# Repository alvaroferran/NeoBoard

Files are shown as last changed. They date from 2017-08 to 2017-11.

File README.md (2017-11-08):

# NeoBoard

<p align="center">
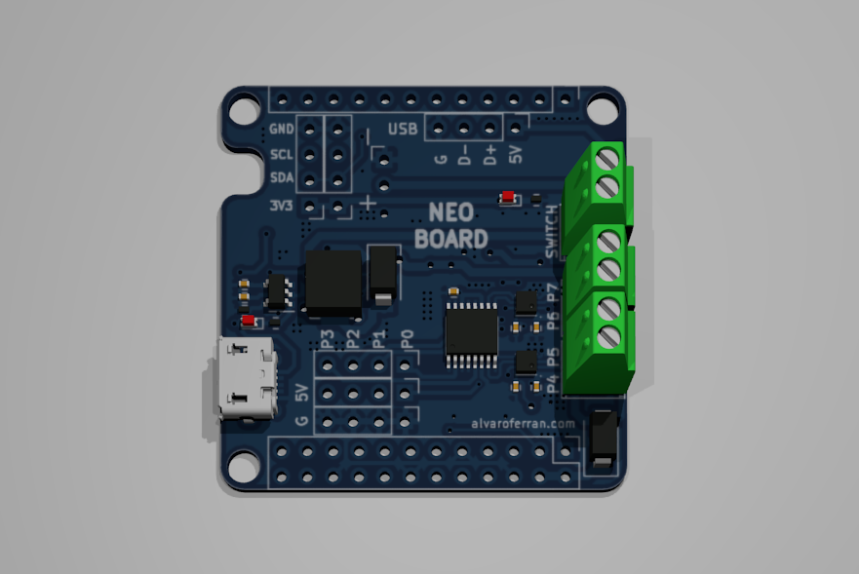
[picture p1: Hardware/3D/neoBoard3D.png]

</p>

<br>

NeoBoard is a robotics controller shield for the [NanoPi Neo Air](http://nanopi.io/nanopi-neo-air.html) SBC. It can drive two DC motors, has four extra 5V GPIOs and an ADC to read the battery level from the Linux board. It also includes a 1S LiPo battery charger, a 3.5A boost circuit to ramp the voltage up to 5V for the motors and a hardware-based motor disconnect in case of low battery.

<p align="center">
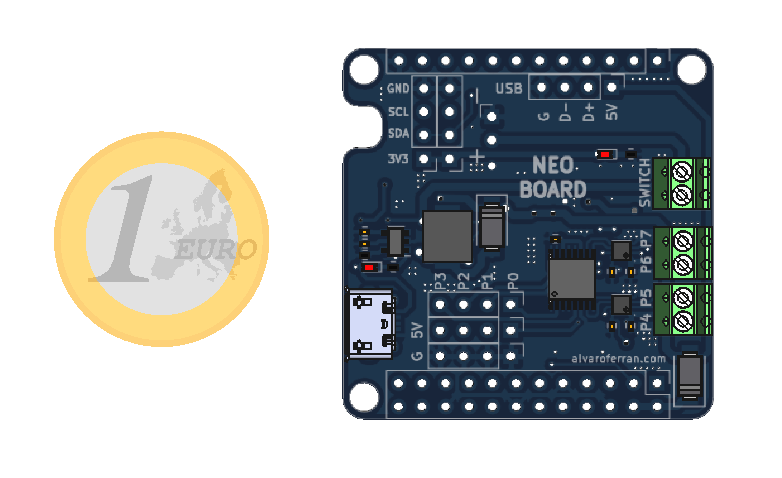
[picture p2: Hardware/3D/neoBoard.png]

</p>

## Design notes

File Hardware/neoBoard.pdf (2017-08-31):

# 3.3V REG

# J2USB BAT CHARGER

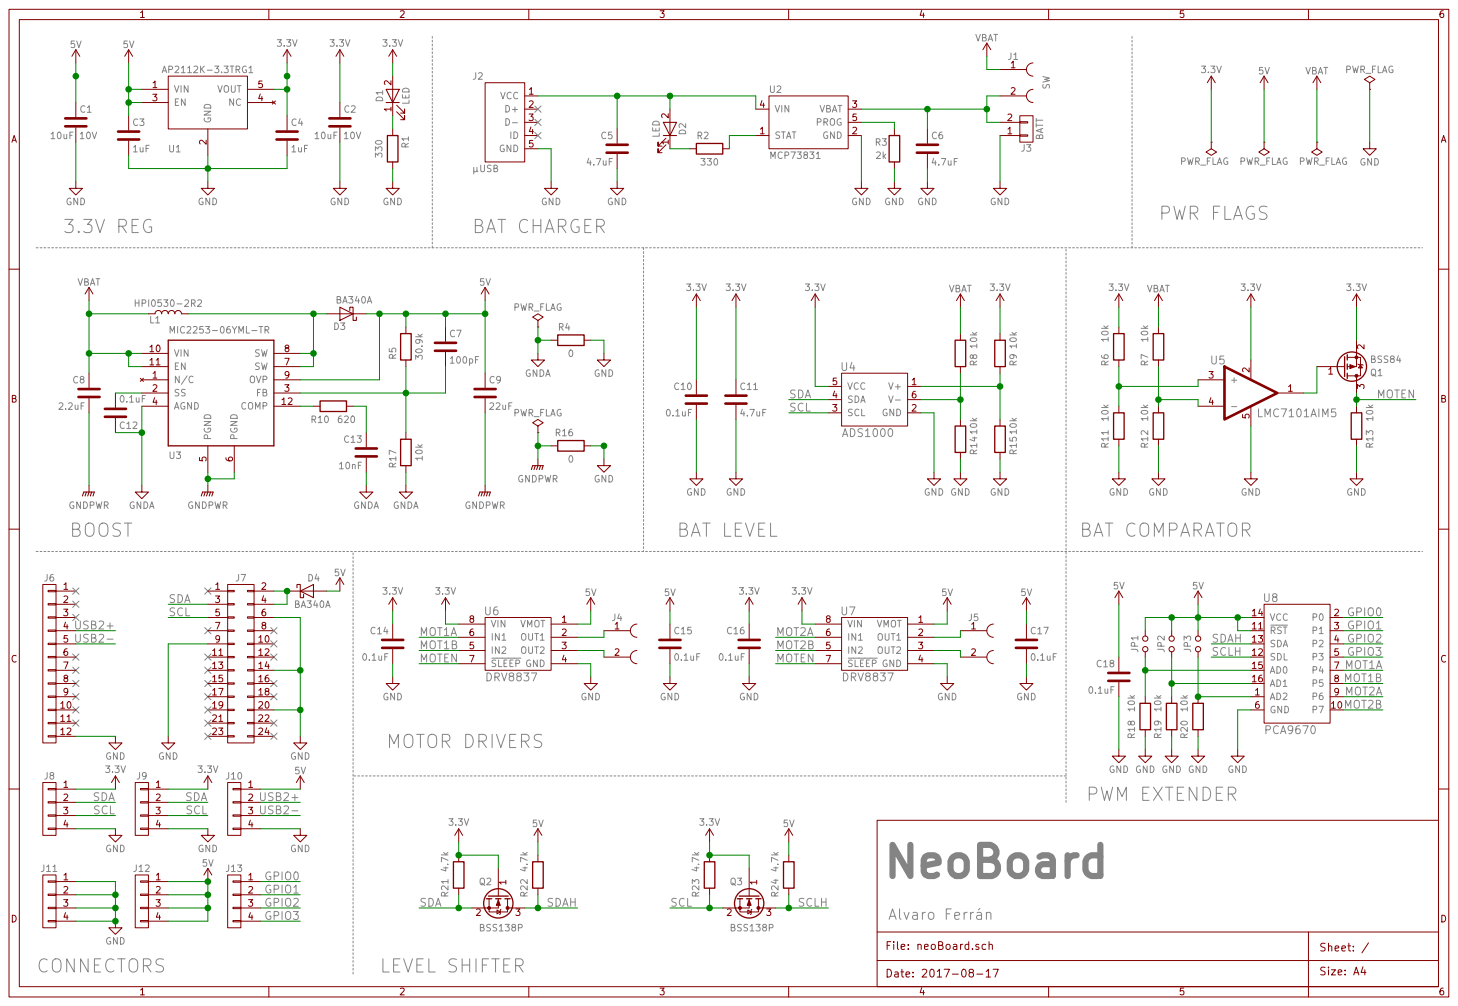
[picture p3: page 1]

6 SW 7 SW 8 OVP 9 VIN 10 EN 11 COMP 12 N/C 1 U3MIC2253-06YML-TR D3BA340A GNDPWR GNDA GNDPWR GNDA GNDA GNDPWR BOOST

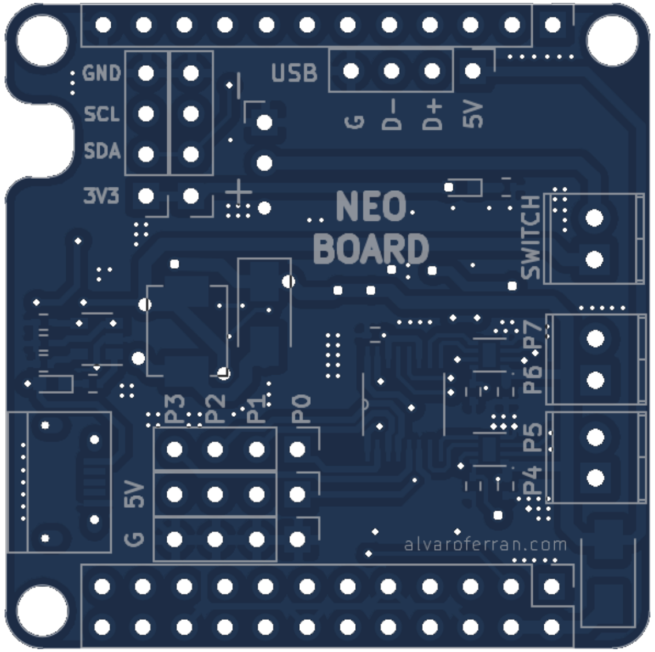
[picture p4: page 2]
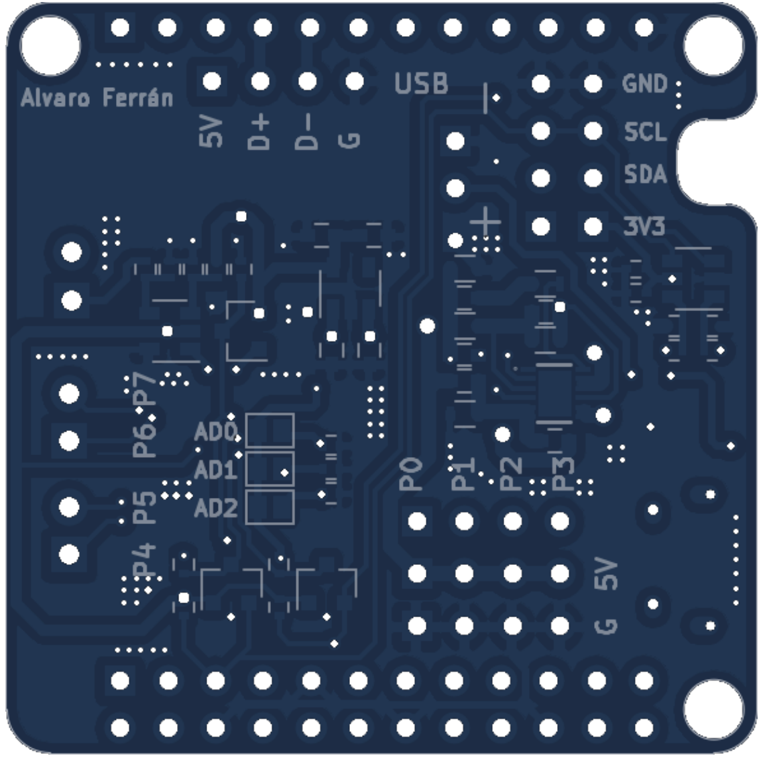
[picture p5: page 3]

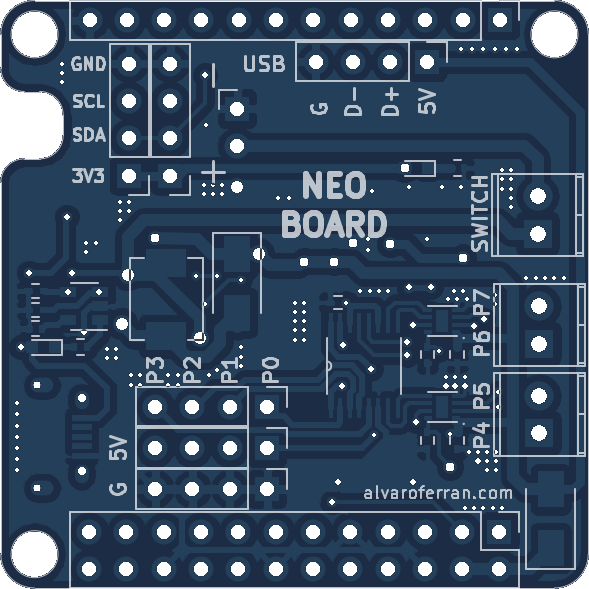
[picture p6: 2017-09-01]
Hardware/Silkscreen/Silkscreen1-Top.png

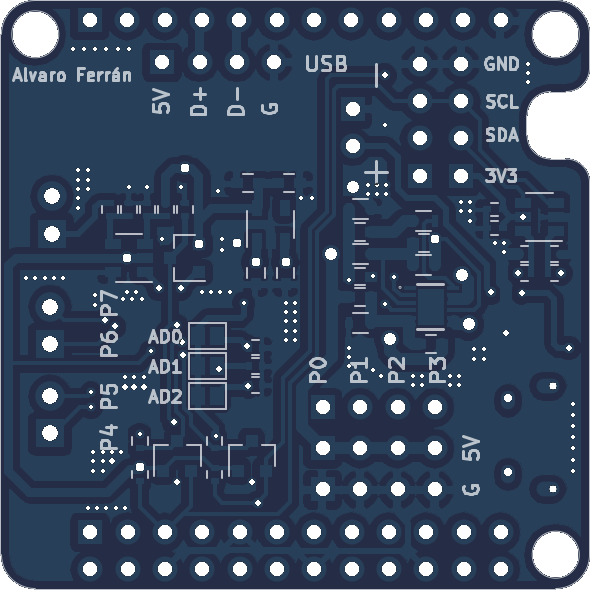
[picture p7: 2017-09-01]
Hardware/Silkscreen/Silkscreen2-Bottom.png

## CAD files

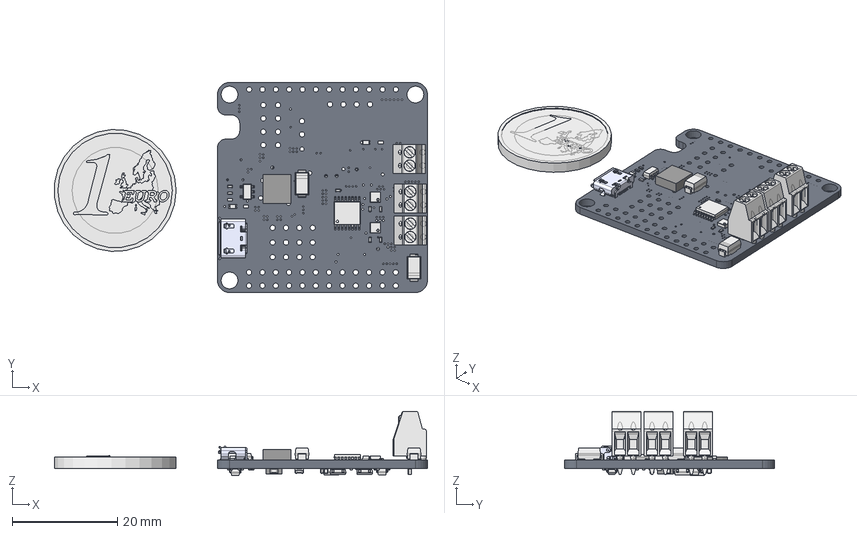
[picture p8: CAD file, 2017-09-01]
Hardware/3D/neoBoard.fcstd
71.0 x 40.0 x 12.3 mm
Board
R1
R2
R6
R7
R8
R11
R12
R13
R14
R18
R19
R20
R21
R22
R3
R9
R15
R23
R24
Q3
Q2
Q1
R16
R5
R4
R10
R17
C8
C13
C1
C2
C3
C4
C7
C9
C12
C5
C6
C10
C11
C14
C15
C16
C17
C18
U8
U1
U2
U5
U4
D1
D2
D3
D4
microUSB
J1
J4
J5
U6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

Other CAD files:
Hardware/Outline/outline.fcstd
Hardware/3D/neoBoard.obj
Hardware/Outline/outline.dxf

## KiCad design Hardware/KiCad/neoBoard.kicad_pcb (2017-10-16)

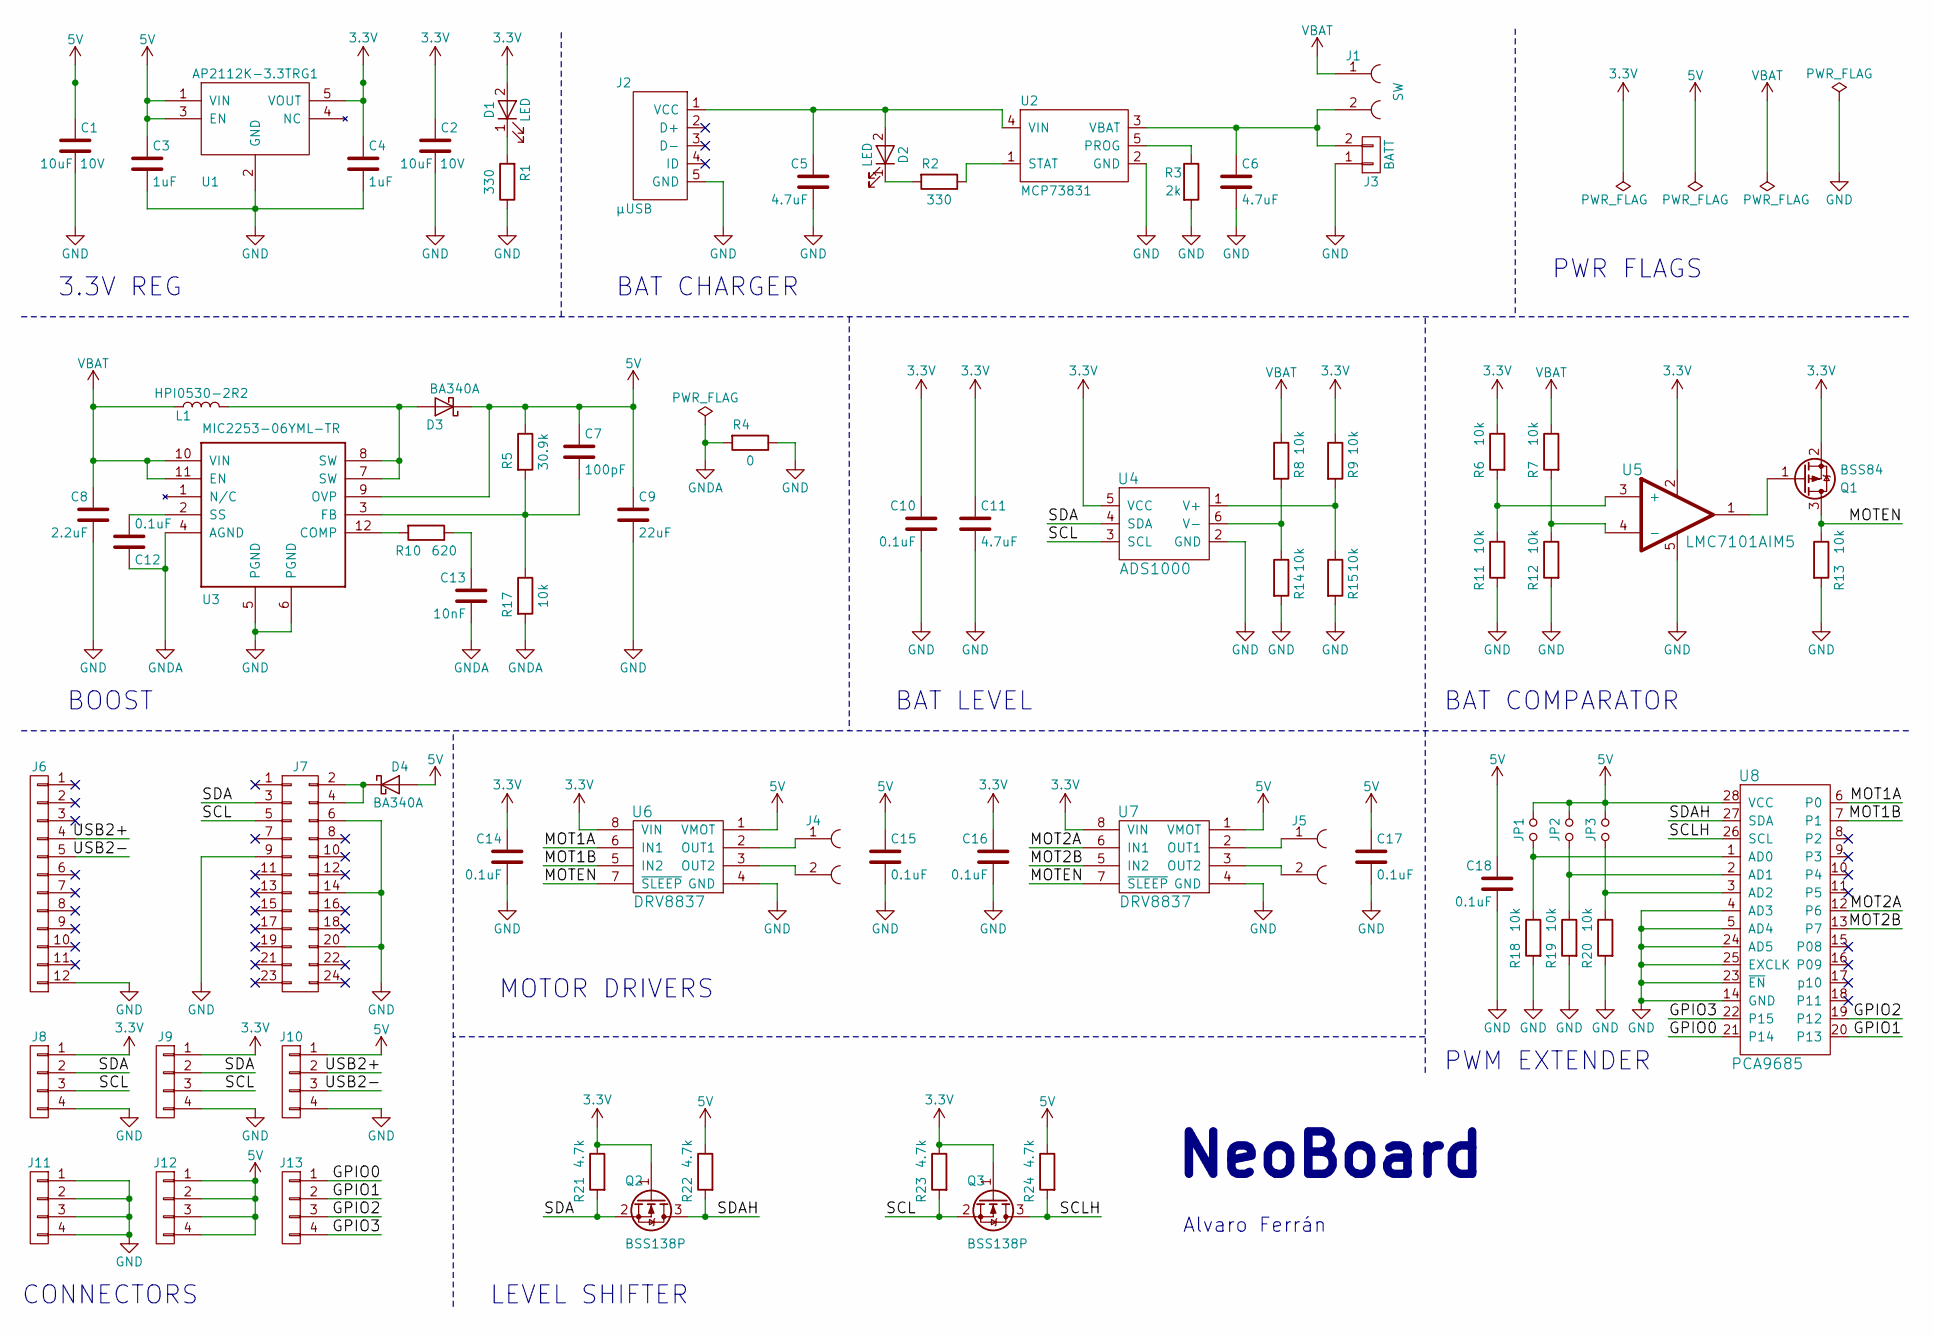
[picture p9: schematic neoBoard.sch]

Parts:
C1, C2: 10uF 10V; C_0603
C3, C4: 1uF; C_0603
C5, C6, C11: 4.7uF; C_0402
C7: 100pF; C_0603
C8: 2.2uF; C_0603
C9: 22uF; C_0805
C10, C14, C15, C16, C17, C18: 0.1uF; C_0402
C12: 0.1uF; C_0603
C13: 10nF; C_0603
D1, D2: LED; LED_0603
D3, D4: BA340A; D_SMA
J1: SW; TerminalBlock_Pheonix_MPT-2.54mm_2pol
J2: μUSB; USB_Micro-B
J3: BATT; Pin_Header_Angled_1x02_Pitch2.54mm
J4, J5: TerminalBlock_Pheonix_MPT-2.54mm_2pol
J6: CONN_01X12_Straight; Pin_Header_Straight_1x12_Pitch2.54mm
J7: CONN_02X12_Straight; Pin_Header_Straight_2x12_Pitch2.54mm
J8, J9, J10, J11, J12, J13: CONN_01X04_Straight; Pin_Header_Straight_1x04_Pitch2.54mm
JP1, JP2, JP3: Jumper_NO; GS2
L1: HPI0530-2R2
Q1: BSS84; SOT-23
Q2, Q3: BSS138P; SOT-23
R1, R2: 330; R_0402
R3: 2k; R_0402
R4: 0; R_0603
R5: 30.9k; R_0603
R6, R7, R8, R9, R11, R12, R13, R14, R15, R18, R19, R20: 10k; R_0402
R10: 620; R_0603
R17: 10k; R_0603
R21, R22, R23, R24: 4.7k; R_0402
U1: AP2112K-3.3TRG1; SOT-23-5
U2: MCP73831; SOT-23-5
U3: MIC2253-06YML-TR
U4: ADS1000; SOT-23-6
U5: LMC7101AIM5; SOT-23-5
U6, U7: DRV8837; WSON-8
U8: PCA9685; TSSOP-28

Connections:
3.3V: C2.1, C4.1, C10.1, C11.1, C14.1, C16.1, D1.2 (A), J8.1, J9.1, Q1.2 (S), Q2.1 (G), Q3.1 (G), R6.1, R9.1, R21.1, R23.1, U1.5 (VOUT), U4.5 (VCC), U5.2, U6.8 (VIN), U7.8 (VIN)
5V: C1.1, C3.1, C7.1, C9.1, C15.1, C17.1, C18.1, D3.1 (K), D4.2 (A), J10.1, J12.1, J12.2, J12.3, J12.4, JP1.2, JP2.2, JP3.2, R5.1, R22.1, R24.1, U1.1 (VIN), U1.3 (EN), U3.9 (OVP), U6.1 (VMOT), U7.1 (VMOT), U8.28 (VCC)
/GPIO0: J13.1, U8.21 (P14)
/GPIO1: J13.2, U8.20 (P13)
/GPIO2: J13.3, U8.19 (P12)
/GPIO3: J13.4, U8.22 (P15)
/MOT1A: U6.6 (IN1), U8.6 (P0)
/MOT1B: U6.5 (IN2), U8.7 (P1)
/MOT2A: U7.6 (IN1), U8.12 (P6)
/MOT2B: U7.5 (IN2), U8.13 (P7)
/MOTEN: Q1.3 (D), R13.1, U6.7 (~SLEEP), U7.7 (~SLEEP)
/SCL: J7.5, J8.3, J9.3, Q3.2 (S), R23.2, U4.3 (SCL)
/SCLH: Q3.3 (D), R24.2, U8.26 (SCL)
/SDA: J7.3, J8.2, J9.2, Q2.2 (S), R21.2, U4.4 (SDA)
/SDAH: Q2.3 (D), R22.2, U8.27 (SDA)
/USB2+: J6.4, J10.2
/USB2-: J6.5, J10.3
GND: C1.2, C2.2, C3.2, C4.2, C5.2, C6.2, C8.2, C9.2, C10.2, C11.2, C14.2, C15.2, C16.2, C17.2, C18.2, J2.5 (GND), J3.1, J6.12, J7.6, J7.9, J7.14, J7.20, J8.4, J9.4, J10.4, J11.1, J11.2, J11.3, J11.4, R1.1, R3.2, R4.1, R11.2, R12.2, R13.2, R14.2, R15.2, R18.2, R19.2, R20.2, U1.2 (GND), U2.2 (GND), U3.5 (PGND), U3.6 (PGND), U4.2 (GND), U5.5, U6.4 (GND), U7.4 (GND), U8.4 (AD3), U8.5 (AD4), U8.14 (GND), U8.23 (~EN), U8.24 (AD5), U8.25 (EXCLK)
GNDA: C12.1, C13.2, R4.2, R17.2, U3.4 (AGND)
unnamed: C5.1, D2.2 (A), J2.1 (VCC), U2.4 (VIN)
unnamed: C6.1, J1.2, J3.2, U2.3 (VBAT)
unnamed: C7.2, R5.2, R17.1, U3.3 (FB)
unnamed: C12.2, U3.2 (SS)
unnamed: C13.1, R10.1
unnamed: D1.1 (K), R1.2
unnamed: D2.1 (K), R2.2
unnamed: D3.2 (A), L1.2, U3.7 (SW), U3.8 (SW)
unnamed: D4.1 (K), J7.2, J7.4
unnamed: J4.1, U6.2 (OUT1)
unnamed: J4.2, U6.3 (OUT2)
unnamed: J5.1, U7.2 (OUT1)
unnamed: J5.2, U7.3 (OUT2)
unnamed: JP1.1, R18.1, U8.1 (AD0)
unnamed: JP2.1, R19.1, U8.2 (AD1)
unnamed: JP3.1, R20.1, U8.3 (AD2)
unnamed: Q1.1 (G), U5.1
unnamed: R2.1, U2.1 (STAT)
unnamed: R3.1, U2.5 (PROG)
unnamed: R10.2, U3.12 (COMP)
unnamed: R6.2, R11.1, U5.3 (+)
unnamed: R7.2, R12.1, U5.4 (-)
unnamed: R8.2, R14.1, U4.6 (V-)
unnamed: R9.2, R15.1, U4.1 (V+)
VBAT: C8.1, J1.1, L1.1, R7.1, R8.1, U3.10 (VIN), U3.11 (EN)

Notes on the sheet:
NeoBoard
Alvaro Ferrán
3.3V REG
BAT CHARGER
BOOST
MOTOR DRIVERS
BAT COMPARATOR
BAT LEVEL
PWM EXTENDER
CONNECTORS
LEVEL SHIFTER
PWR FLAGS

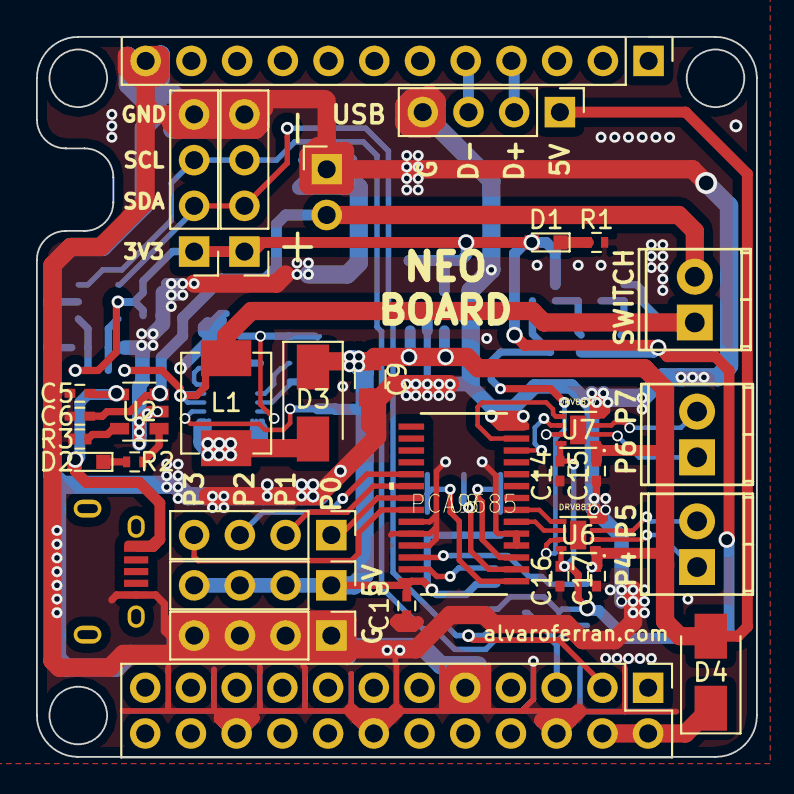
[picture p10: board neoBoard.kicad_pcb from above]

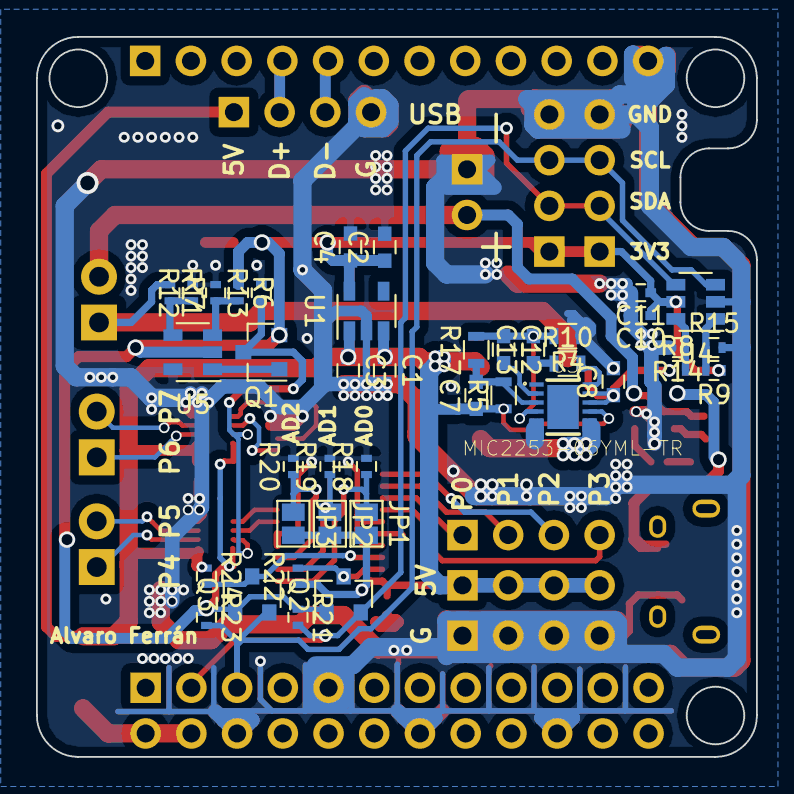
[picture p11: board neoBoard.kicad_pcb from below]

Board: 2 copper layers, 40.0 x 40.0 mm, 73 parts (40 on the bottom side), 44 nets.

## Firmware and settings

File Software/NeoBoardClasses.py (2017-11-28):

#!/usr/bin/python

import smbus
import time


"""
Helper functions used throughout the classes.
"""
def mapValues(vx, v1, v2, n1, n2):
    # v1 start of range, v2 end of range, vx the starting number
    percentage = (vx - v1) / (v2 - v1)
    # n1 start of new range, n2 end of new range
    return (n2 - n1) * percentage + n1


def constrain(value, minVal, maxVal):
    if value < minVal:
        value = minVal
    if value > maxVal:
        value = maxVal
    return value




class PCA9685:

    """
    Class to intialize and control the PCA9685 PWM generator, including setting
    voltages in form of percentages or driving servos.
    """

    def __init__(self, address=0x40):
        self.bus = smbus.SMBus(0)    # /dev/i2c-0
        self.address = address
        self.pins = [14, 13, 12, 15, 0, 1, 6, 7]    # P0-P7
        self.frequency = 200    # Default with 25Mhz oscillator
        self.startConfig()

    def writePWM(self, pin, percentage):
        percentage = constrain(percentage, 0, 100)
        percentage = int(percentage * 40.95)     # 0-100% -> 0-4095
        self.writeValues(pin, percentage)

    def writeServo(self, pin, angle):
        angle = constrain(angle, 0, 180)
        # Limit values at 50Hz, found experimentally
        self.servoMin = 128.0
        self.servoMax = 512.0
        scale = self.frequency / 50.0
        value = int(mapValues(angle, 0.0, 180.0, self.servoMin*scale,
                    self.servoMax*scale))
        self.writeValues(pin, value)

    def setFrequency(self, frequency):
        # Set SLEEP bit to 1 first
        conf = self.bus.read_byte_data(self.address, 0x00)
        conf = (conf & 0xEF) | 0x10
        self.bus.write_byte_data(self.address, 0x00, conf)
        # Calculate prescale from datasheet
        frequency = constrain(frequency, 24, 1526)
        prescale = int(round(25000000.0/(4096*frequency))-1)
        self.bus.write_byte_data(self.address, 0xFE, prescale)
        # Actual frequency due to rounding errors
        self.frequency = 25000000/(4096*(prescale+1))
        # Reset chip
        self.startConfig()

    def writeAllOff(self):
        # Turn all outputs to LOW
        off = [0x00, 0x00, 0x00, 0x10]
        self.bus.write_i2c_block_data(self.address, 0xFA, off)

    def writeValues(self, index, value):
        regH = (value & 0xF00) >> 8
        regL = value & 0xFF
        vals = [0x00, 0x00, regL, regH]   # LedOnL, LedOnH, LedOffL, LedOffH
        channel = self.pins[index]
        self.bus.write_i2c_block_data(self.address, 0x06+channel*4, vals)

    def startConfig(self):
        # Set SLEEP to 0 to start oscillator
        self.bus.write_byte_data(self.address, 0x00, 0x01)
        time.sleep(0.001)
        # Set AutoIncrement to 1
        self.bus.write_byte_data(self.address, 0x00, 0xA0)
        # Set OUTDRV and OUTNE0 to 1 in MODE2 register
        self.bus.write_byte_data(self.address, 0x01, 0x05)
        time.sleep(0.001)
        self.writeAllOff()




class ADS1000:

    """
    Class to intialize and read battery levels from the ADS1000 ADC
    """

    def __init__(self, address=0x48):
        self.bus = smbus.SMBus(0)    # /dev/i2c-0
        self.address = address

    def readBattery(self):
        rawData = self.bus.read_i2c_block_data(self.address, 0x00, 2)
        # From datasheet, 12bit ADC: 4 last bits of first byte and second byte
        adcH = rawData[0] & 15                 # Take lower 4 bits
        adc = adcH << 8 | rawData[1]           # Create 12bit word
        adc = self.twos_complement(adc, 12)    # Find decimal equivalent
        voltage = (1.625-adc*3.25/2048)*2      # 3V3 is actually at 3.25V, YMMV
        percent = mapValues(voltage, 3.3, 4.04, 0, 100)
        if percent > 100:                      # Max voltage when not charging
            percent = 100
        return (voltage, percent)

    def twos_complement(self, input_value, num_bits):
        mask = 2**(num_bits - 1)
        return -(input_value & mask) + (input_value & ~mask)
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

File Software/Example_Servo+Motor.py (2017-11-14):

#!/usr/bin/python

import time
from NeoBoardClasses import PCA9685, mapValues

PCA9685_ADDRESS = 0x40
PCA9685 = PCA9685(PCA9685_ADDRESS)

PCA9685.setFrequency(50)

valMin = 0
valMax = 100
increment = 1
delay = 0.01

mot1 = 4
mot2 = 5
servo = 0

# Create list of speed values
speedValues = []
for speed in range(valMin, valMax, increment):
    speedValues.append(speed)
for speed in range(valMax, valMin, -increment):
    speedValues.append(speed)
for speed in range(valMin, -valMax, -increment):
    speedValues.append(speed)
for speed in range(-valMax, -valMin, increment):
    speedValues.append(speed)

# Iterate through different speeds
for speed in speedValues:
    print(speed)
    angle = mapValues(speed, float(valMin), float(valMax), 0.0, 180.0)
    if speed >= 0:
        PCA9685.writePWM(mot1, speed)
        PCA9685.writePWM(mot2, 0)
        PCA9685.writeServo(servo, angle)
    else:
        PCA9685.writePWM(mot1, 0)
        PCA9685.writePWM(mot2, -speed)
        PCA9685.writeServo(servo, -angle)
    time.sleep(delay)

# Turn off all outputs
PCA9685.writeAllOff()

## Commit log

2017-08-18 Schematic: battery charger
    [placa.sch]
2017-08-22 Schematic: battery inversion protection
    [placa.sch]
2017-08-22 Schematic: motor decoupling caps added
    [placa.sch]
2017-08-23 Schematic: ADC added
    [placa.sch]
2017-08-23 Schematic: PWM added
    [placa.sch]
2017-08-24 Schematic: Connectors added
    [placa.sch]
2017-08-24 Schematic: ERC passed
    [placa.sch]
2017-08-24 Schematic: Packages changed
    [placa.sch]
2017-08-25 Schematic: Packages changed
    Schematic: Packages changed
    [placa.sch]
2017-08-28 Schematic: Level shifter
    [placa.kicad_pcb, placa.sch]
2017-08-28 Schematic: Protection diode
    [placa.kicad_pcb, placa.sch]
2017-08-28 Schematic: Batt inv removed
    [placa.kicad_pcb, placa.sch]
2017-08-29 Board: components in place
    [placa.kicad_pcb, placa.sch]
2017-08-31 3D model
    [neoBoard.fcstd]
2017-09-05 3D: OBJ added
    [neoBoard.obj]
2017-09-05 3D scale corrected
    [neoBoard.obj]
2017-09-05 3D scale corrected OBJ
    [neoBoard.obj]
2017-09-11 PCB updated
    [neoBoard.kicad_pcb]
2017-09-22 Improved GND connections
    [neoBoard.kicad_pcb]
2017-09-22 Change PCA9670 to PCA9685
    [neoBoard.kicad_pcb, neoBoard.sch]
2017-09-25 Charger track changed from 16mil to 24mil
    [neoBoard.kicad_pcb]
2017-10-06 Boost circuit re-routed
    [neoBoard.kicad_pcb, neoBoard.sch]
2017-10-06 Silkscreen fixes
    [neoBoard.kicad_pcb]
2017-10-16 Silkscreen changes
    [neoBoard.kicad_pcb]
2017-11-08 Created Hardware folder
    [neoBoard.fcstd, neoBoard.kicad_pcb, neoBoard.obj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]
2017-11-14 Servo control and frequency selection added
2017-11-14 Servo control example added
2017-11-14 Map function renamed to avoid confusion with native function
    [NeoBoardClasses.py]
2017-11-14 Motor and servo example added
